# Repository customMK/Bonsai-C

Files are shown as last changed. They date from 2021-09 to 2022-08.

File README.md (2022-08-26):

# Bonsai C

Brought to you by customMK, Bonsai C is a family of open source microcontroller boards intended for custom mechanical keyboards using STM32F ARM microcontrollers. Designed to be a drop-in-replacement for Proton C rev 2 (and thus Pro Micros as well), Bonsai C incorporates several design and manufactring improvements, including being "JLCPCB-ready".

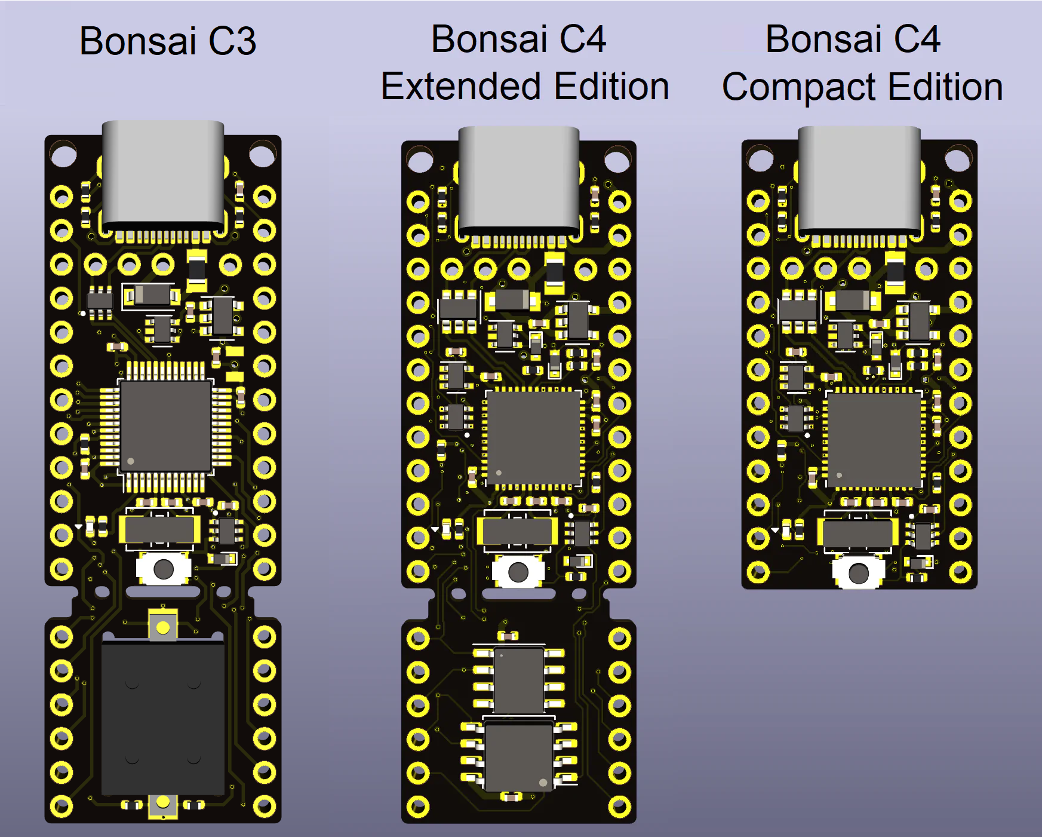
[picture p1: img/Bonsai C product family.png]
Bonsai C product family


# Bonsai C3

Bonsai C3 features an STM32F303 microcontroller, and has the exact same electrical functionality as the (now unavailable) Proton C. More info on Bonsai C3 can be found [here](https://github.com/customMK/Bonsai-C/tree/main/C3)

# Bonsai C4 Extended Edition

Bonsai C4 Extended Edition features an STM32F411 microcontroller. It is designed to be a drop-in-repalcement for Proton C, making it also compatible with ProMicro-based designs. The board is [available for purchase at customMK](https://shop.custommk.com/products/bonsai-c4-microcontroller-board?variant=41508980850884), and can be built through JLCPCB as well. In addition to the board being usable in DIY keyboard kits, Bonsai C4 can serve as a useful reference and starting point for keyboard designers planning to use STM32F411 becuase it incorporates the hardware necessary consistent USB DFU boot.

More info on Bonsai C4 Extended Edition can be found [here](https://github.com/customMK/Bonsai-C/tree/main/C4%20extended), as well as a Bonsai C4 product guide [here](https://custommk.github.io/#/Bonsai-C4/quick-start) (work in progress)

# Bonsai C4 Compact Edition

Bonsai C4 Compact Edition is electrically identical to the Bonsai C4 Extended Edition, however, the Compact Edition physically matches the form factor of a ProMicro instead of Proton C. While lower part of the Extended Edition can be snapped off to make it the size of a ProMicro, doing this removes the FRAM and Flash memory chips. On the Compact Edition, the FRAM and Flash memory chips are instead mounted to the back side of the PCB. The board is [available for purchase at customMK](https://shop.custommk.com/products/bonsai-c4-microcontroller-board?variant=41508980818116)

More info on Bonsai C4 Compact Edition can be found [here](https://github.com/customMK/Bonsai-C/tree/main/C4%20compact), as well as a Bonsai C4 product guide [here](https://custommk.github.io/#/Bonsai-C4/quick-start) (work in progress). There is also a [JLCPCB-ready version of the compact edition](https://github.com/customMK/Bonsai-C/tree/main/C4%20compact%20JLCPCB), which meets hole size and trace/space requirements for JLCPCB, and uses parts availalble through JLCPCB.

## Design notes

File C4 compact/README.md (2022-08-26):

# Bonsai C4 Compact Edition

Brought to you by customMK, Bonsai C4 Compact Edition is an open source microcontroller board featuring an STM32F411CEU6 microcontroller. It is designed to be a drop-in-replacement for Proton C rev 2 and Pro Micro. It has the same circuit as the Bonsai C4 Extended Edition, with the exception that the PCB is made shorter (to match the ProMicro length) and the on-board FRAM and flash memory are located on the back of the PCB. Bonsai C4 Compact Edtiion is most useful for pre-existing keyboard designs that only have the physical space available for a ProMicro (Kyria, Sofle, Lily58, etc.), while retaining the full capability of Bonsai C4 Extended Edtion (aside from the extra pins).

For a version of Bonsai C4 with more pins that matches the length of a Proton C, please see Bonsai C4 Extended Edition found [here](https://github.com/customMK/Bonsai-C/tree/main/C4%20extended)

## Contents

- [Images](#images)
- [Pinout and DMA streams](#pinout-and-dma-streams)
- [Bonsai C4 and JLCPCB](#bonsai-c4-and-jlcpcb)
- [Usage in split keyboards](#usage-in-split-keyboards)
- [License](#license)

## Images

Bonsai C4 schematic
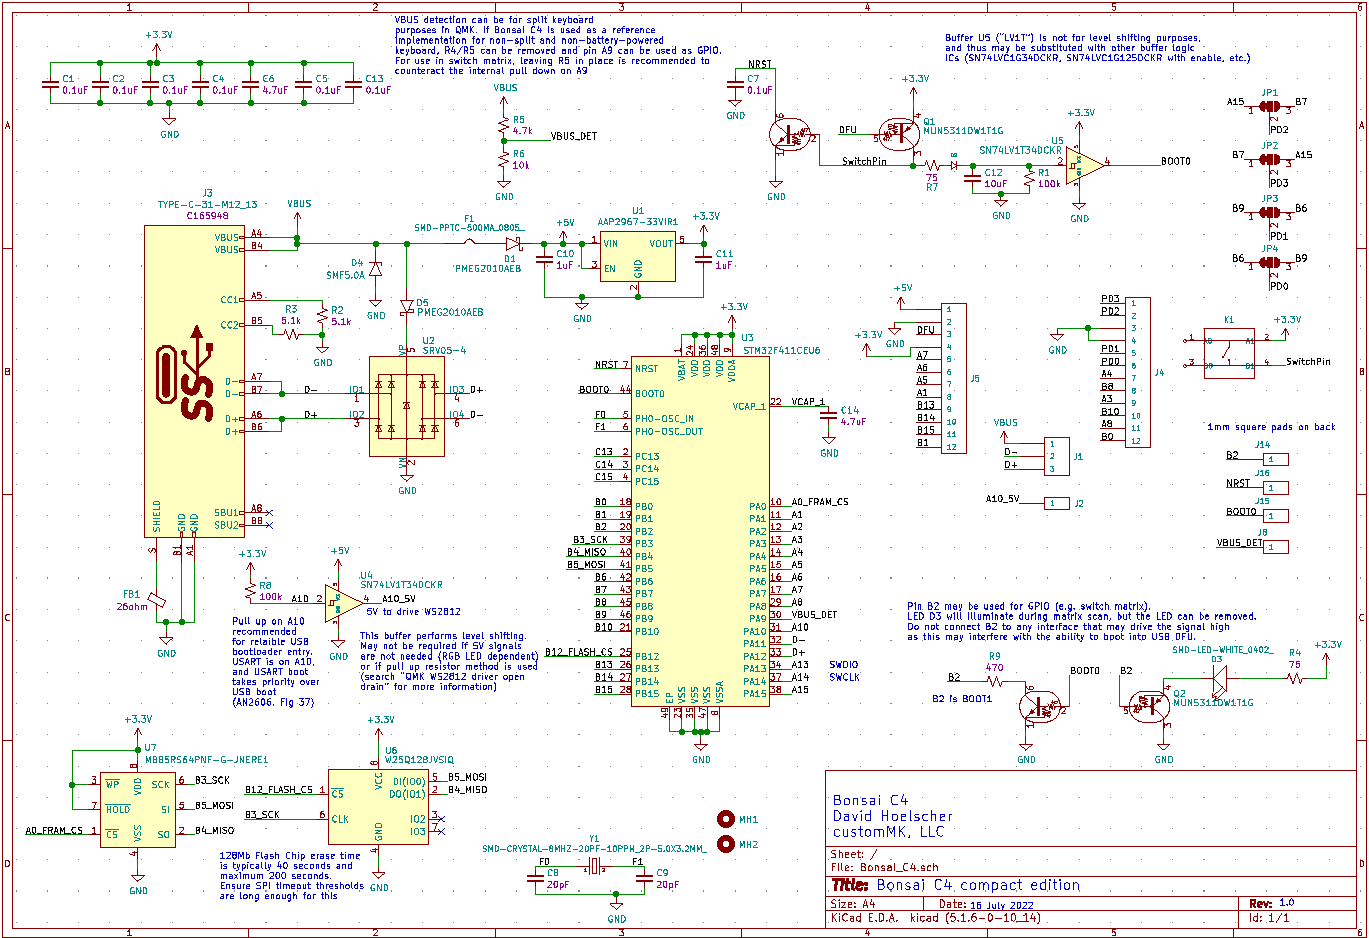
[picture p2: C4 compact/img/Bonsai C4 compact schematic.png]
Bonsai C4 Compact Edition schematic


Bonsai C4 compact edition PCB front photo

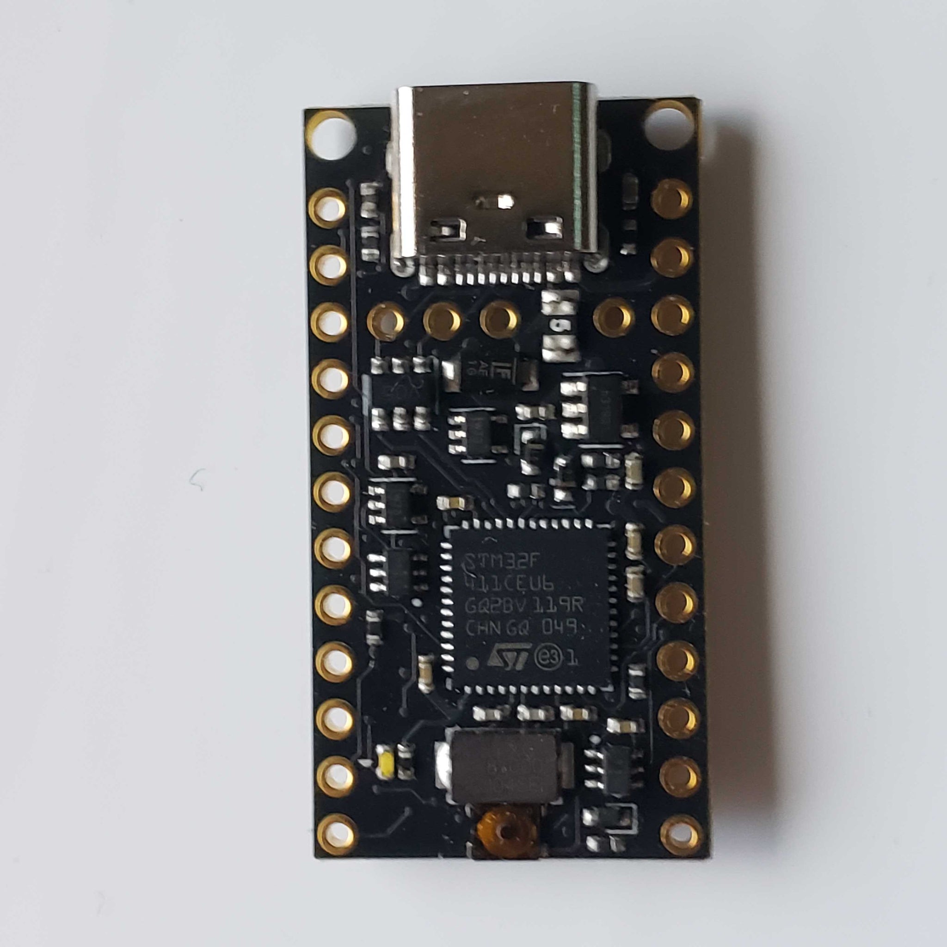
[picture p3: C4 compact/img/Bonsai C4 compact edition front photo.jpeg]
Bonsai C4 compact edition front photo


Bonsai C4 compact edition PCB back photo

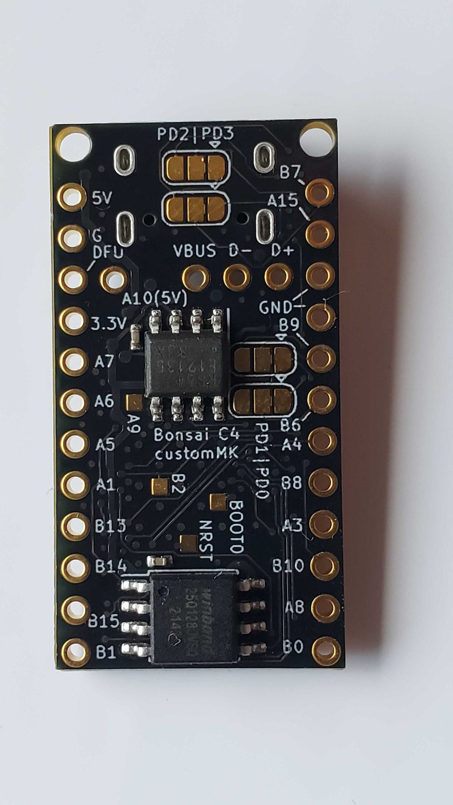
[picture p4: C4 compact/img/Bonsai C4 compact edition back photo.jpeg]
Bonsai C4 compact edition back photo


Bonsai C4 compact edition PCB front

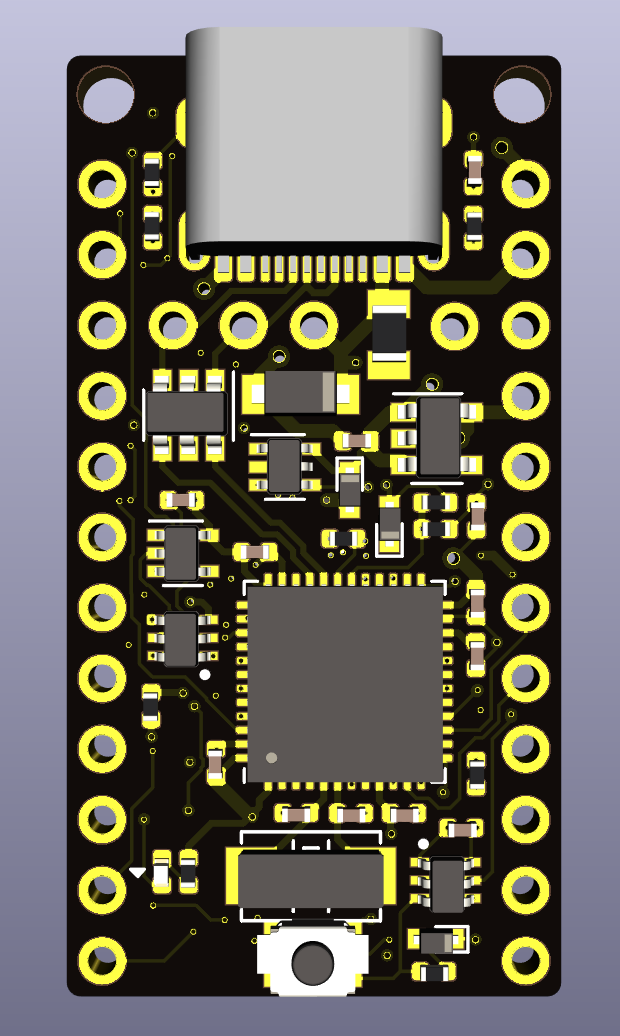
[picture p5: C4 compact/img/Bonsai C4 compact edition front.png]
Bonsai C4 compact edition front


Bonsai C4 compact edition PCB back

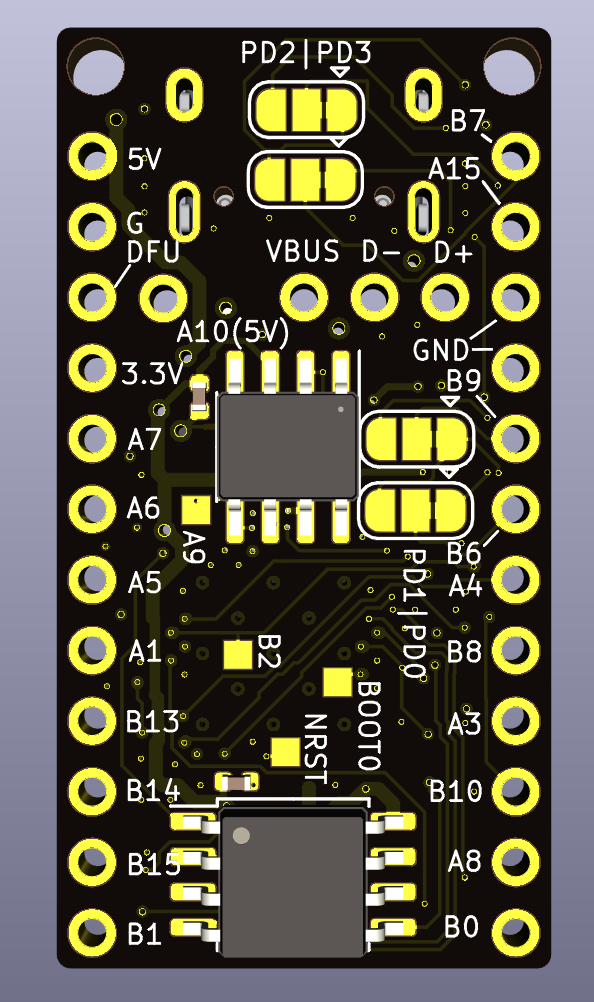
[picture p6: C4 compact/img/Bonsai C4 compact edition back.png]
Bonsai C4 compact edition back


# Pinout and DMA streams

Detailed pinout information, peripherals available on each pin, and a DMA stream management utility (to avoid DMA conflicts) can be found [here](https://docs.google.com/spreadsheets/d/1FY-Vt8GbN7uX89lh9176jPXvGJELREzGpuhMts9ds38/edit?usp=sharing).

# Bonsai C4 and JLCPCB

The STM32F411CEU6 has a large thermal pad on the back that prevents signal vias and traces from being placed under the microcontroller. As such, it is challenging to route all the traces in a way that fits the original form factor of the ProMicro/Proton C/Bonsai C. To keep the same form factor, via-in-pad is necessary. For consistent results in PCB production, this ususaly means doing a non-conductive via fill, cap, and planarize operation, which JLCPCB does not do. 

While the JLCPCB process may not be ideal for such a layout, we have now successfully built and tested prototype of Bonsai C4 Compact Edition built by JLCPCB (as of March 2022) at a cost of around $35 per PCB for five PCBs. Some parts had to be swapped out, hole sizes were changes, and traces modified, but the files used to produce these JLCPCB can be found [here](https://github.com/customMK/Bonsai-C/tree/main/C4%20compact%20JLCPCB)

# Usage in split keyboards

Limitations the STM32F411CEU6 are of particular concern to designers of split keyboards. Specifially, due to design decisions by ST, it is difficult to support all possible USART_TX pin locations on a single PCB. To help overcome this issue, solder bridges have been provided that allow certain pins to be swapped. Using ProMicro pinout labeling as a reference, only D0, D1, D2, and D3 are supported for half duplex split communications. Without any modification to Bonsai C4, ProMicro D0 (as B6 on the STM32F411) and D2 (as A15 on the STM32F411) are supported for soft serial use.

There are two pairs of solder bridges on the back of the board. Cutting the traces between these solder bridges (e.g. with a razor blade/Exacto knife/etc.) and then soldering across the opposite pads will swap either the D0 and D1 pins, or the D2 and D3 pins (depending on which pair of solder bridges is being modified).

It should be noted that the default of assignment of STM32F411 A15 to ProMicro D2 was done intentionally, even though technically, as a USART TX pin, it seems like it should be wired to ProMicro D3 instead. The reason for this is that many more keyboards tend to use ProMicro D2 for half duplex soft serial communciations (as compared to those which use ProMicro D3). Unlike Atmega32U4 on the ProMicro, the STM32F411 can only use the USART TX pin for this purpose, so the USART TX pin (A14) has been wired to ProMicro D2. The solder bridge opposite the USB connector can be used to swap these back, but it seems better to support the more common use by default without requiring modification to the board.

[Bonsai C4 Product Guide](https://custommk.github.io/#/Bonsai-C4/quick-start) (work in progress)

# Split keyboard reset

Many split keyboard designs use the same PCB for left and right sides. This requires one of the microcontroller boards to be flipped over for installation, which makes the reset button inaccessible. A simple workaround is to un-solder the reset switch, and then solder it between the DFU and GND pins. Temporarily connecting DFU and GND performs the same function as the reset switch; specifically, it reboots the microcontroller into bootloader mode.

## License

Open sourced under the [CERN 2.0 permissive license](LICENSE.md).

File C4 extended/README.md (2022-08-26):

# Bonsai C4 Extended Edition

Brought to you by customMK, Bonsai C4 Extended Edition is an open source microcontroller board featuring an STM32F411CEU6 microcontroller. It is designed to be a drop-in-replacement for Proton C rev 2 and Pro Micro. 

For a more compact version of Bonsai C4 that matches the length of a Pro Micro (for physical backwards compatibility reasons), please see Bonsai C4 Compact Edition found [here](https://github.com/customMK/Bonsai-C/tree/main/C4%20compact)

## Contents

- [Images](#images)
- [Pinout and DMA streams](#pinout-and-dma-streams)
- [Bonsai C4 and JLCPCB](#bonsai-c4-and-jlcpcb)
- [Usage in split keyboards](#usage-in-split-keyboards)
- [License](#license)

## Images

Bonsai C4 Extended Edition Schematic
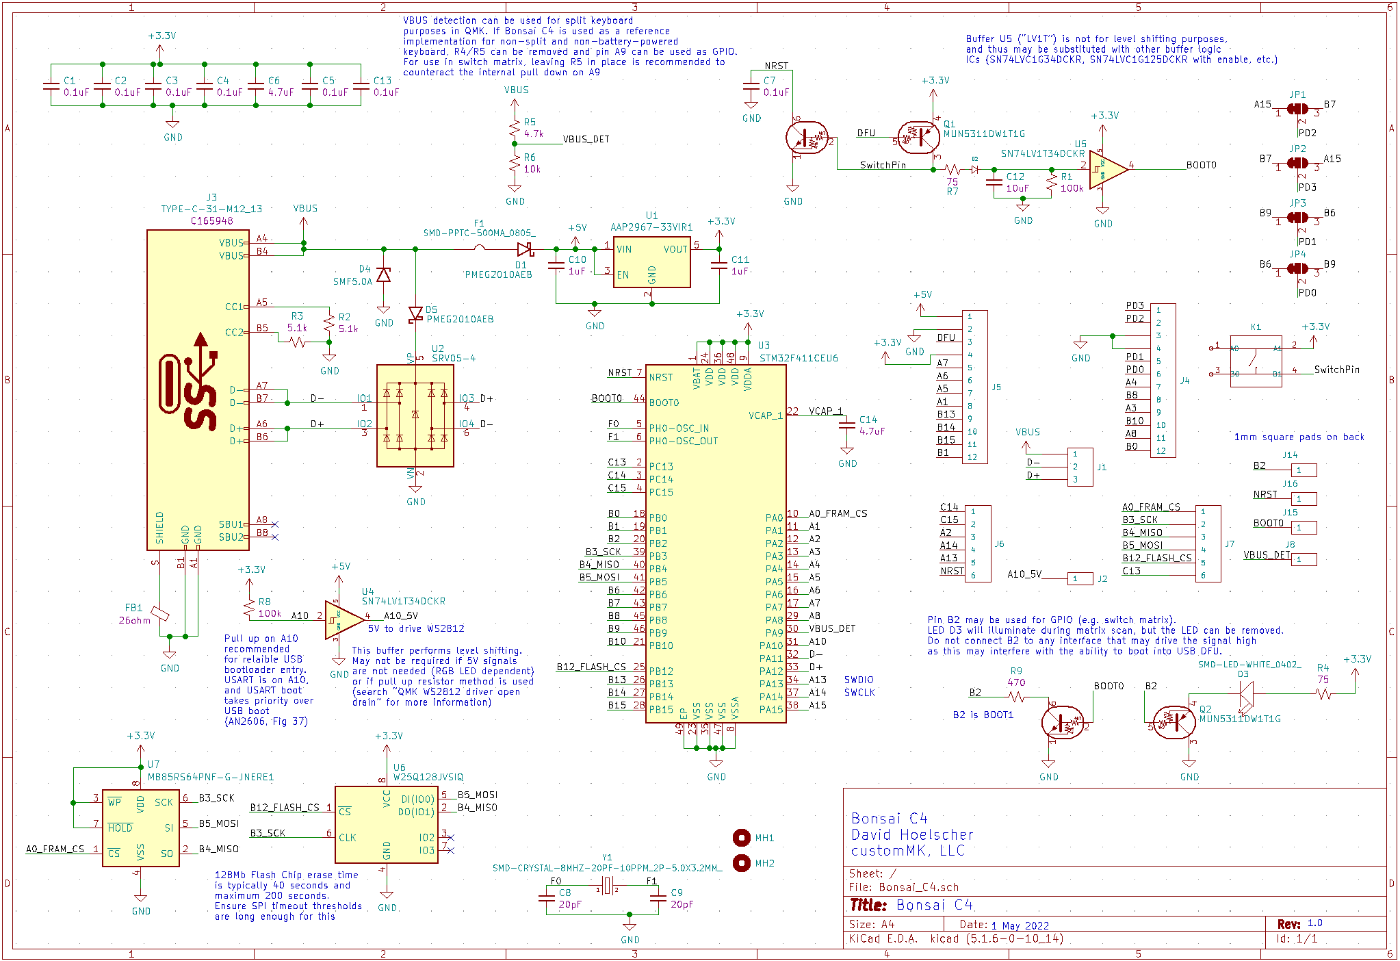
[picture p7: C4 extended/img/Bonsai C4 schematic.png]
Bonsai C4 Extended Edition schematic

Bonsai C4 Extended Edition front photo

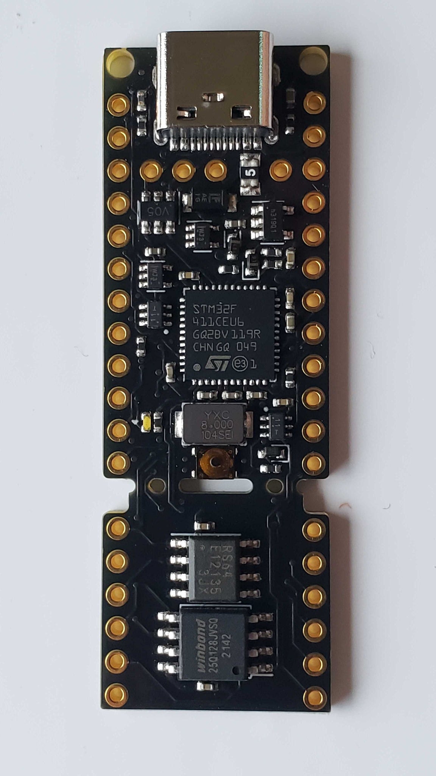
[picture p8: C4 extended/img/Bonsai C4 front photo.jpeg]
Bonsai C4 front photo

Bonsai C4 PCB Extended Edition back photo

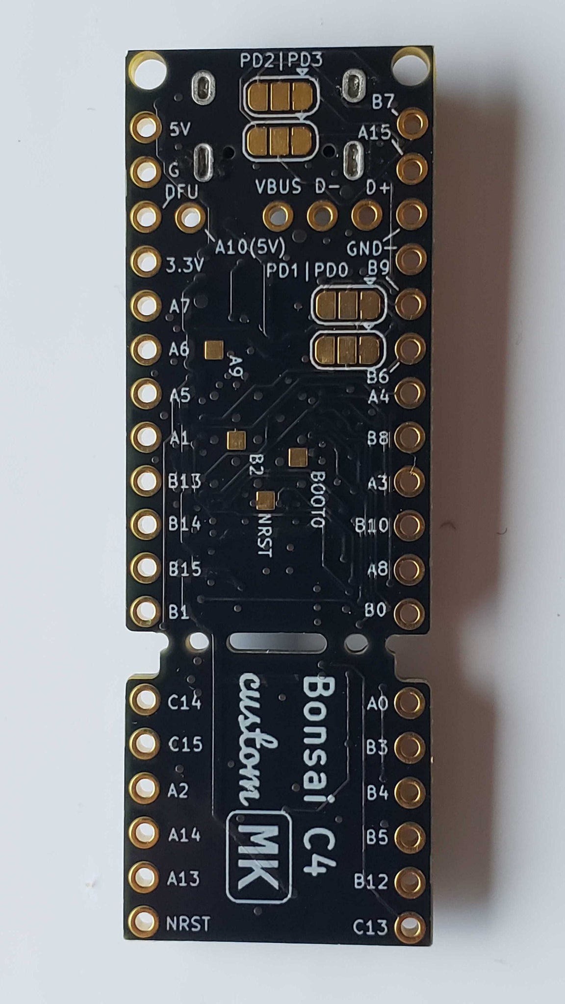
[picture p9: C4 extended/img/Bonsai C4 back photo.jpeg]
Bonsai C4 back photo

Bonsai C4 Extended Edition PCB front

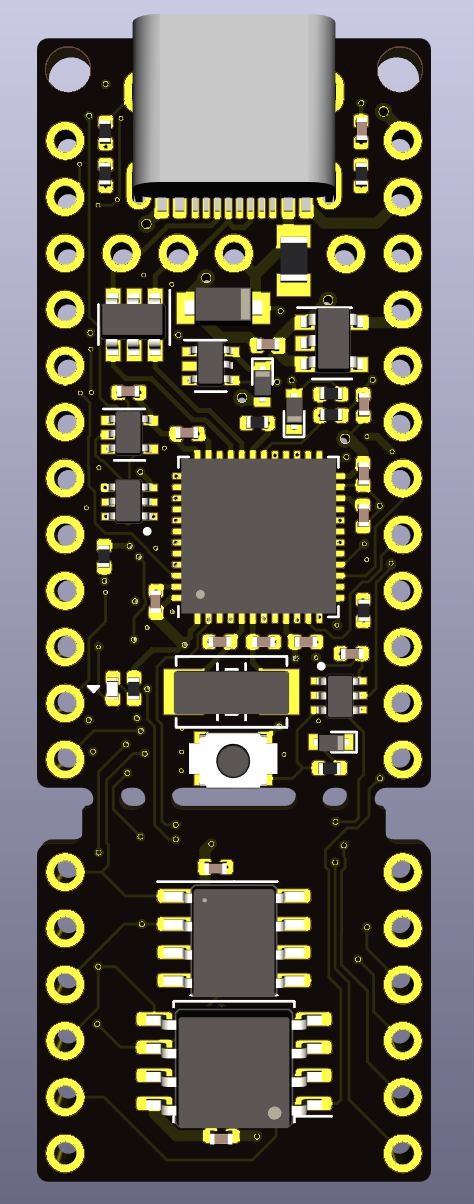
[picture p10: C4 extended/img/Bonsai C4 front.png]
Bonsai C4 front

Bonsai C4 PCB Extended Edition PCB back 

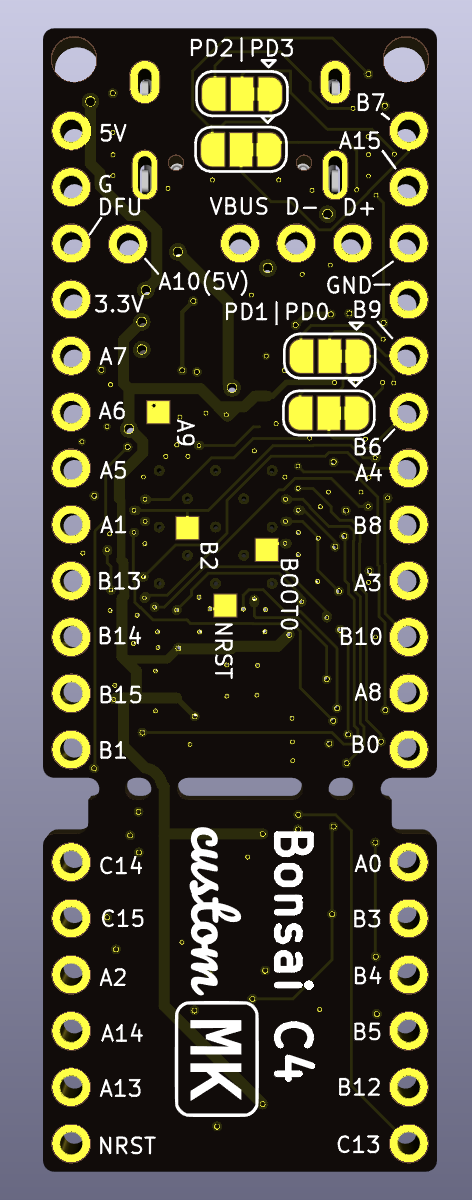
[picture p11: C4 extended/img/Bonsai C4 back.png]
Bonsai C4 back


# Pinout and DMA streams

Detailed pinout information, peripherals available on each pin, and a DMA stream management utility (to avoid DMA conflicts) can be found [here](https://docs.google.com/spreadsheets/d/1FY-Vt8GbN7uX89lh9176jPXvGJELREzGpuhMts9ds38/edit?usp=sharing).

# Bonsai C4 and JLCPCB

The STM32F411CEU6 has a large thermal pad on the back that prevents signal vias and traces from being placed under the microcontroller. As such, it is challenging to route all the traces in a way that fits the original form factor of the ProMicro/Proton C/Bonsai C. To keep the same form factor, via-in-pad is necessary. For consistent results in PCB production, this ususaly means doing a non-conductive via fill, cap, and planarize operation, which JLCPCB does not do. 

While the JLCPCB process may not be ideal for such a layout, we have now successfully built and tested prototype of Bonsai C4 Compact Edition built by JLCPCB (as of March 2022) at a cost of around $35 per PCB for five PCBs. Some parts had to be swapped out, hole sizes were changes, and traces modified, but the files used to produce these JLCPCB can be found [here](https://github.com/customMK/Bonsai-C/tree/main/C4%20compact%20JLCPCB)

# Usage in split keyboards

Limitations the STM32F411CEU6 are of particular concern to designers of split keyboards. Specifially, due to design decisions by ST, it is difficult to support all possible USART_TX pin locations on a single PCB. To help overcome this issue, solder bridges have been provided that allow certain pins to be swapped. Using ProMicro pinout labeling as a reference, only D0, D1, D2, and D3 are supported for half duplex split communications. Without any modification to Bonsai C4, ProMicro D0 (as B6 on the STM32F411) and D2 (as A15 on the STM32F411) are supported for soft serial use.

There are two pairs of solder bridges on the back of the board. Cutting the traces between these solder bridges (e.g. with a razor blade/Exacto knife/etc.) and then soldering across the opposite pads will swap either the D0 and D1 pins, or the D2 and D3 pins (depending on which pair of solder bridges is being modified).

It should be noted that the default of assignment of STM32F411 A15 to ProMicro D2 was done intentionally, even though technically, as a USART TX pin, it seems like it should be wired to ProMicro D3 instead. The reason for this is that many more keyboards tend to use ProMicro D2 for half duplex soft serial communciations (as compared to those which use ProMicro D3). Unlike Atmega32U4 on the ProMicro, the STM32F411 can only use the USART TX pin for this purpose, so the USART TX pin (A14) has been wired to ProMicro D2. The solder bridge opposite the USB connector can be used to swap these back, but it seems better to support the more common use by default without requiring modification to the board.

[Bonsai C4 Product Guide](https://custommk.github.io/#/Bonsai-C4/quick-start) (work in progress)

# Split keyboard reset

Many split keyboard designs use the same PCB for left and right sides. This requires one of the microcontroller boards to be flipped over for installation, which makes the reset button inaccessible. A simple workaround is to un-solder the reset switch, and then solder it between the DFU and GND pins. Temporarily connecting DFU and GND performs the same function as the reset switch; specifically, it reboots the microcontroller into bootloader mode.

## License

Open sourced under the [CERN 2.0 permissive license](LICENSE.md).

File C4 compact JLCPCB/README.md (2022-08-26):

# Bonsai C4 Compact Edition, JLCPCB

Brought to you by customMK, Bonsai C4 Compact Edition for JLCPCB is the same as Bonsai C4 Compact Edition, except minor adjustments were made to comply with JLCPCB trace/space and hole size requirements, as well as to use parts generally available through JLCPCB

Note that the EEPROM/FRAM chip and the flash memory chips are on the back side of this board. They can be soldered on by hand using JLCPCB's economical assembly service, or JLCPCB can solder them on at higher expense using their standard assembly service.

## Contents

- [Images](#images)
- [License](#license)

## Images

Bonsai C4 Compact Edition schematic
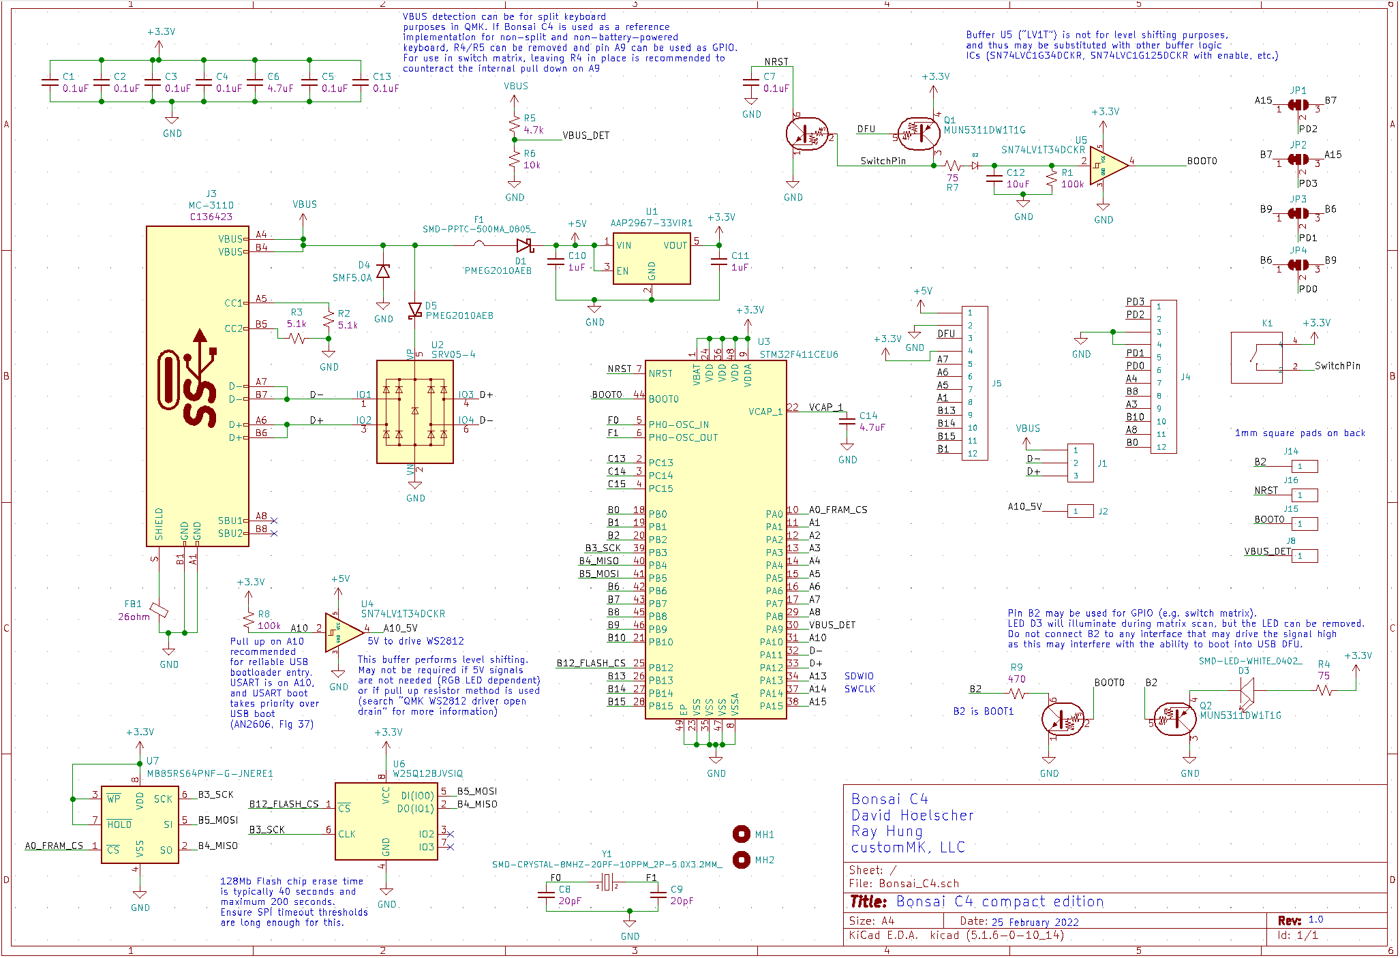
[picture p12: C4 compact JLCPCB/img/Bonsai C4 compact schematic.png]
Bonsai C4 compact edition schematic


Bonsai C4 Compact Edition front produced by JLCPCB

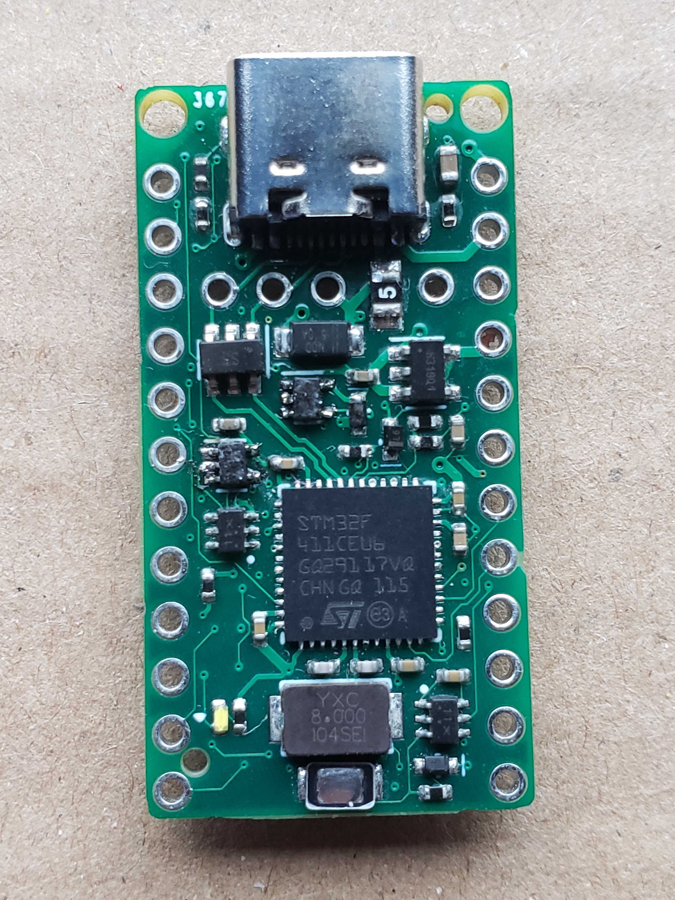
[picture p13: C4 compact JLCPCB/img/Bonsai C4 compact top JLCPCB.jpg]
Bonsai C4 compact edition front

Bonsai C4 Compact Edition back produced by JLCPCB

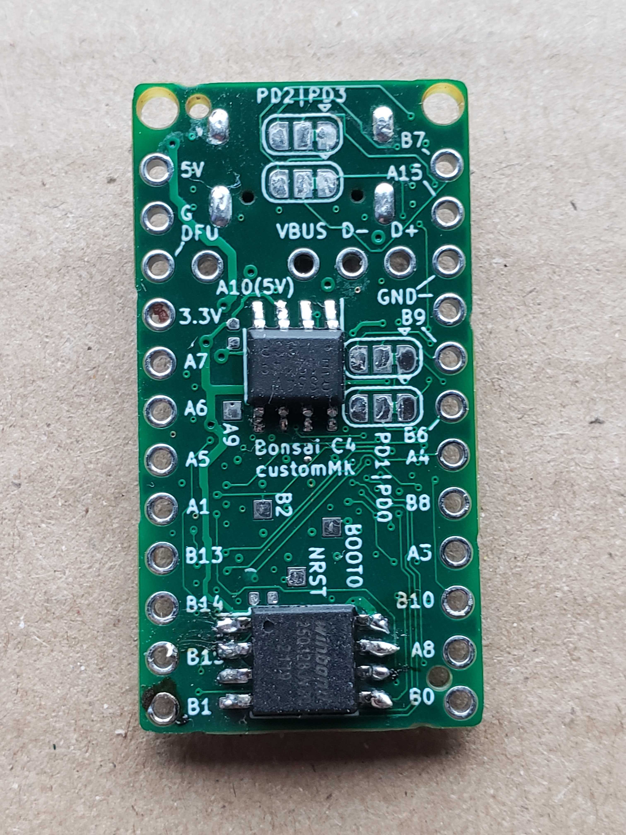
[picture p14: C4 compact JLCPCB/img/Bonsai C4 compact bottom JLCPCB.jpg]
Bonsai C4 compact edition back


## License

Open sourced under the [CERN 2.0 permissive license](LICENSE.md).

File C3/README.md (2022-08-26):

# Bonsai C3

## Contents

- [Images](#images)
- [Background](#background)
- [Comparison to Proton C](#comparison-to-proton-c)
- [Build information](#build-information)
- [License](#license)

## Images

Bonsai C3 schematic

Bonsai C3 schematic

Bonsai C3 fabricated by JLCPCB (disregard the extra width, 20mm minimum width used to be JLCPCB requirement)



Bonsai C3 PCB front

Bonsai C3 front

Bonsai C3 PCB back

Bonsai C3 back

Bonsai C3 layers

Bonsai C3 layers

## Background

Bonsai C3 is a general-purpose ARM-based microcontroller board. It was designed to help with the protoype and development of mechanical keyboards, but is versatile enough to be used in a variety of other applications. Mechanical keyboards can use Bonsai C3 as a "plug in" microcontroller board to their own designs sans-microcontroller, or they can incorporate the Bonsai C schmatic and layout directly into a complete keyboard PCB design.

## Comparison to Proton C

Bonsai C3 is designed to be a drop-in-replacement to Proton C, and as such, they are functionally equivalent. However, there are several subtle design differences in contrast to Proton C:

<ul>
  <li>Bonsai C3 uses only parts in the JLCPCB SMT library (including the USB C connector)</li>
  <li>Bonsai C3’s USB data traces are shorter and more direct</li>
  <li>Bonsai C3's USB data traces are designed for the correct impedance, using a 4 layer board design with power and ground planes.</li>
  <li>Bonsai C3’s crystal clock lines are shorter and more direct</li>
  <li>Bonsai C3 adds a ferrite between USB shield and ground, improving EMI (radiated susceptibility and radiated emissions)</li>
  <li>Bonsai C3 connects USB VBUS to the ESD chip instead of the +5V (+5V is polyfuse-limited and reverse-diode-protected)</li>
  <li>Bonsai C3 has correct labeling of the C14 and C15 pads (they are currently swapped in Proton C documentation and PCB silkscreen labeling)</li>
  <li>Bonsai C3 uses ceramic bulk decoupling capacitors instead of tantalum capacitors</li>
  <li>Bonsai C3 avoids via-in-pad (note: via-in-pad without non-conductive epoxy fill can cause solder joints to become starved of solder during assembly)</li>
</ul>

## Build information

Bonsai C3 is a four layer PCB design.

If you plan to fabricate the Bonsai C3 design "as-is" without modificiation, within the "build" folder are two different zip files to make it easier to achieve this:
<ul>
<li><b>Bonsai_C3_Gerbers_Only.zip</b> contains the Gerber files only. If you plan to solder parts on your own, you can simply take the zip file, send it to the PCB fab of your choice, and get boards made.</li>

<li><b>Bonsai_C3_PCBA.zip</b> has the set of files needed to make fully-assembled PCBs; this includes the Gerber files above as well as a BOM and position file for assembly. These files can be provided to most of PCB assembly shops when ordering fully assembled boards. Depending on the assembly shop, it may be necessary to use alternative parts for some of the passive components (depending on where components are sourced from).</li>
</ul>
Included are also JLCPCB-ready BOM and position files, so uploading the design can be done by simply uploading the Gerber zip, BOM file, and CPL file to JLCPCB. However, from time to time, parts may go in and out of stock without suitable replacements in the JLCPCB library, necessitating some tailoring and/or hand soldering of components.

To use the lower cost STM32F303CB microcontroller instead of STM32F303CC, simply edit the BOM file; the footprint is identical between the CC and CB variants.

If you are unable to source the microcontroller directly, keep in mind that with the right equipment (hot air rework station) it is possible to transplant microcontroller from other boards you may have. If you plan to program (and let end users reflash) the microcontroller over USB by using QMK Toolbox, you will want you select a microcontroller that includes an embedded USB bootloader, of which there are relatively few options to choose from:

STM USB DFU

See [here](https://github.com/qmk/qmk_firmware/issues/4194) for more information, particularly yiancar's comment on Oct 22, 2018. 

If you are willing to forego programming over the USB connector, and instead find it acceptable to use a low-cost SWD programmer (like ST-LINK) to flash new firmware onto the microcontroller, then there are many many more microcontroller options to choose from.

## License

Open sourced under the [CERN 2.0 permissive license](LICENSE.md).

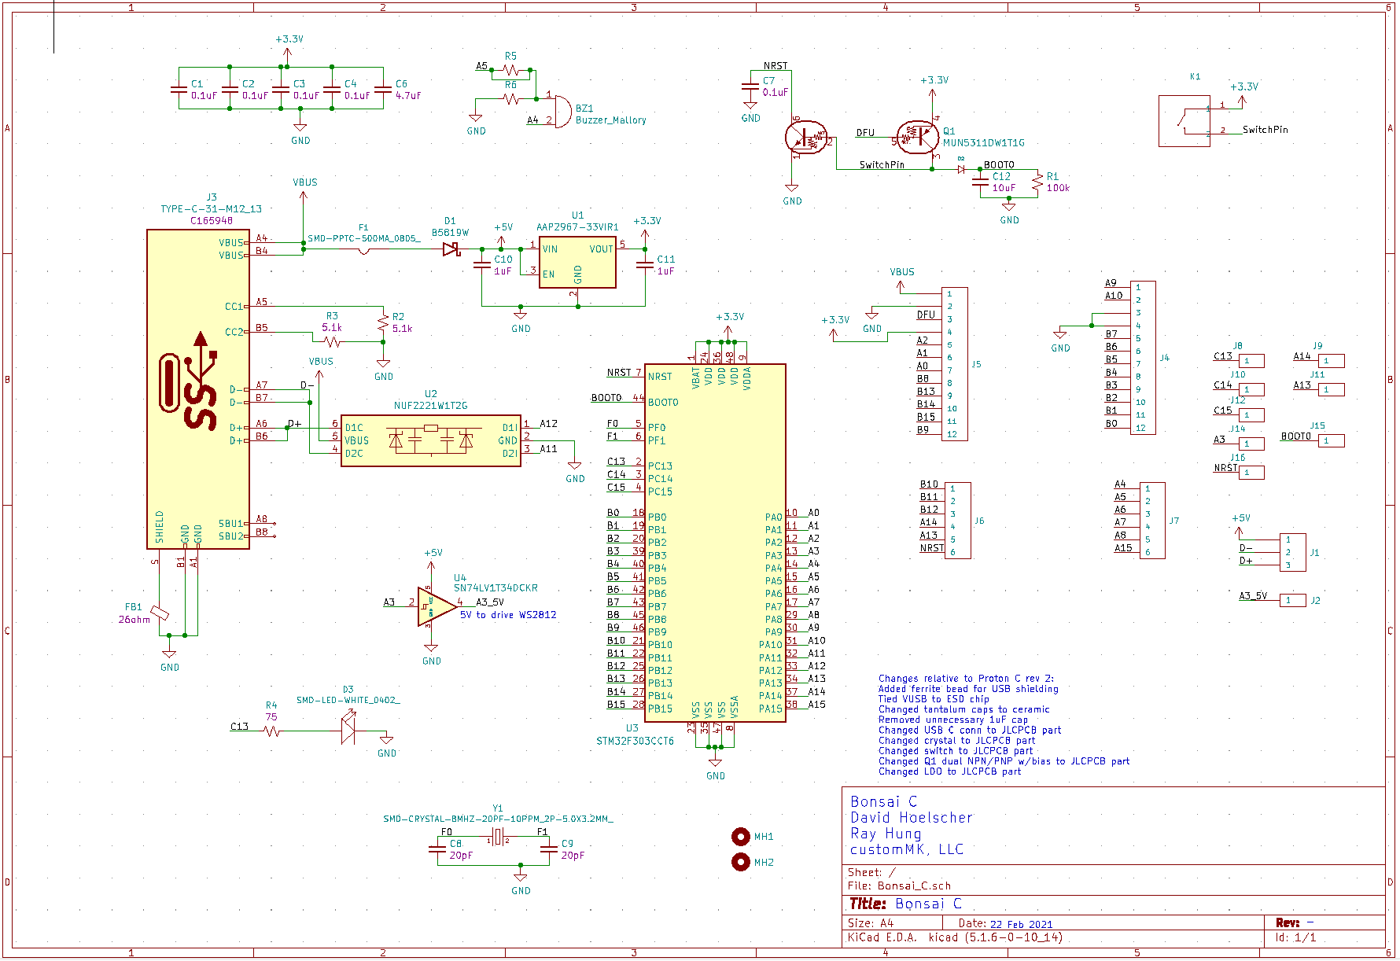
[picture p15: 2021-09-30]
C3/img/Bonsai C schematic.png

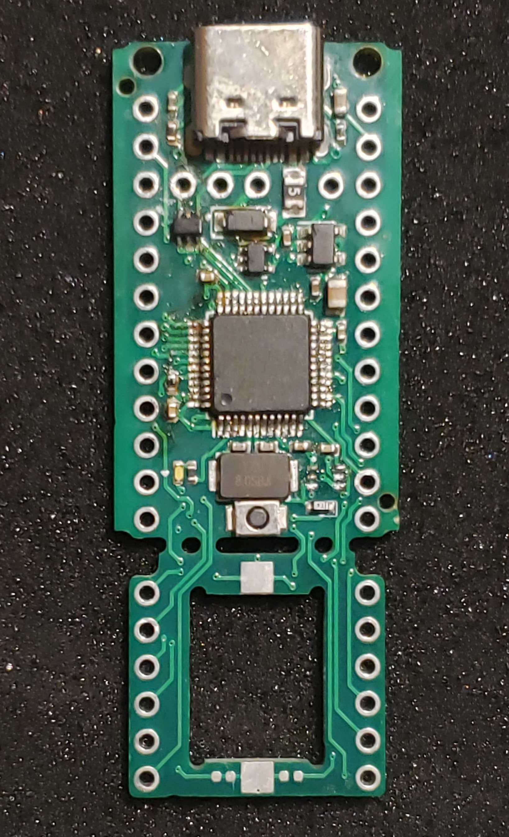
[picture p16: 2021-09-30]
C3/img/Bonsai C JLCPCB photo.jpg

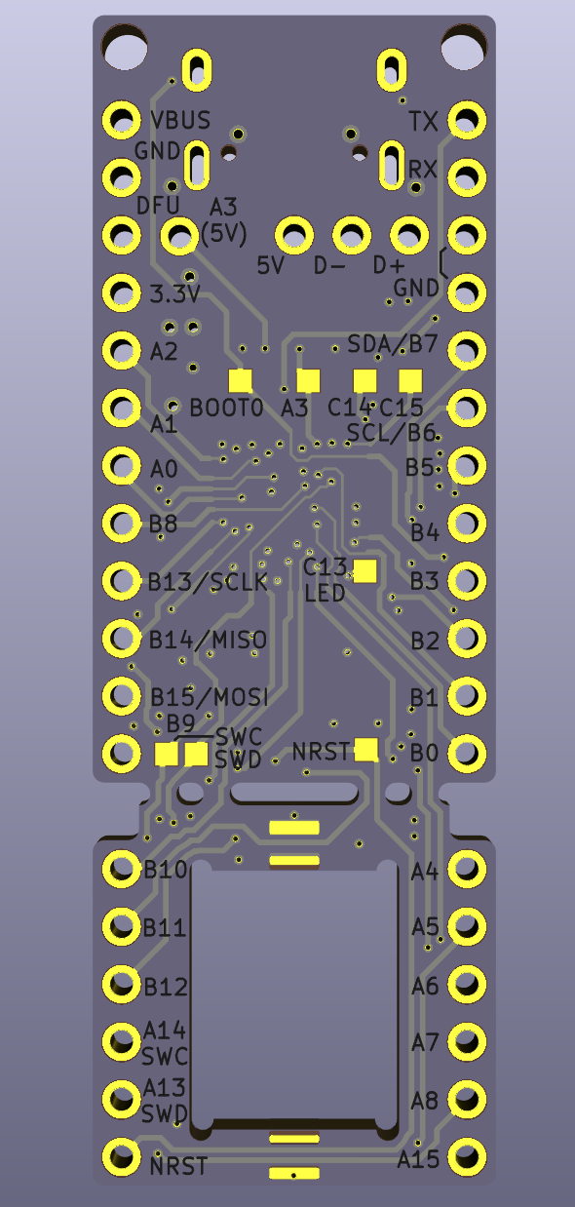
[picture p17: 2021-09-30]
C3/img/Bonsai C back.png

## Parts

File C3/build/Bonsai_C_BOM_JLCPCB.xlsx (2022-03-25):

Bonsai_C_BOM
Designator | Footprint | JLCPCB Part # | Comment | Mfg | Proton C MPN (for reference only) | Proton C Mfg (for reference only)
BZ1 | Buzzer_Mallory | C201047 | KLJ-1102 | KELIKING | AST1109MLTRQ | Mallory
C1, C2, C3, C4, C7 | cap_100nF_16v_0402 | C1525 | CL05B104KO5NNNC | Samsung
C6 | cap_4.7uF_25v_0805 | C1779 | CL21A475KAQNNNE | Samsung
C8, C9 | cap_20pF_50v_0402 | C1554 | 0402CG200J500NT | Guangdong Fenghua Advanced Tech
C10, C11 | cap_1uF_10v_0402 | C52923 | CC0402KRX5R6BB105 | Yageo
C12 | cap_10uF_10v_0402 | C19702 | CL10A106KP8NNNC | Samsung
D1 | B5819W | C8598 | B5819W | Changjiang Electronics Tech
D2 | 1N4148 | C68948 | 1N4148X-TP | Micro Commercial Components
D3 | SMD-LED-WHITE_0402_ | C74342 | 16-219A/T2D-AR2T1QY/3T | Everlight Elec
F1 | SMD-PPTC-500MA_0805_ | C66452 | SMD0805-050 | TECHFUSE
FB1 | fb_0402_26ohm | C668229 | CBG100505U260T | FH
J3 | TYPE-C-31-M12_13 | C165948 | TYPE-C-31-M-12 | Korean Hroparts Elec | 105450-0101 | Molex
K1 | SMD-SWITCH-TACTILE-SPST-NO_2P-2.5MMx3.0MM_ | C231329 | B3U-1000P | Omron | TBE-Q-T/R | Diptronics
Q1 | MUN5311DW1T1G | C152542 | MUN5311DW1T1G | ON Semiconductor | MUN5332DW1T1G | ON Semiconductor
R1 | r_100k_0402_1p | C25741 | 0402WGF1003TCE | Uniroyal
R2, R3 | r_5.1k_0402_1p | C25905 | 0402WGF5101TCE | Uniroyal
R4 | r_75_0402_1p | C25133 | 0402WGF750JTCE | Uniroyal
U1 | AAP2967-33VIR1 | C370742 | AAP2967-33VIR1 | Eutech Microelectronics | MIC5504-3.3YM5 | Microchip
U2 | NUF2221W1T2G | C274624 | NUF2221W1T2G | ON Semiconductor | NUF2221W1T2G | ON Semiconductor
U3 | STM32F303CCT6 | C81523 | STM32F303CCT6 | STMicroelectronics | STM32F303CCT6 | STMicroelectronics
U4 | SN74LV1T34DCKR | C78541 | SN74LV1T34DCKR | Texas Instruments | SN74LV1T34DCKR | Texas Instruments
Y1 | SMD-CRYSTAL-8MHZ-20PF-10PPM_2P-5.0X3.2MM_ | C115962 | X50328MSB2GI | Yangxing Tech | ABM3B-8.000MHZ-10-1-U-T | Abracon

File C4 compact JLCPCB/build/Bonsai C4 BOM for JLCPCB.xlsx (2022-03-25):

Table 1
Comment | Designator | Footprint | LCSC Part Number
cap_100nF_16v_0402 | C1,C2,C3,C4, C7 | C_0402_1005Metric | C1525
cap_20pF_50v_0402 | C8,C9 | C_0402_1005Metric | C1554
cap_1uF_10v_0402 | C10,C11 | C_0402_1005Metric | C52923
cap_10uF_10v_0402 | C12 | C_0402_1005Metric | C19702
cap_4.7uF_10v_0402 | C6,C14 | C_0402_1005Metric | C23733
1N4148 | D2 | D_SOD-523 | C68948
SMD-LED-WHITE_0402_ | D3 | LED_0402 | C74342
SMF5.0A | D4 | D_SOD-123FL | C193402
PMEG2010AEB | D1,D5 | D_SOD-523 | C282563
SMD-PPTC-500MA_0805_ | F1 | F0805 | C66452
fb_0402_26ohm | FB1 | R_0402_1005Metric | C668229
MC-311D | J3 | MC-311D | C136423
SMD-SWITCH-TACTILE-SPST-NO_2P-2.0MMx3.5MM_ | K1 | SW2-SMD-2.0X3.5X0.45MM | C398737
MUN5311DW1T1G | Q1,Q2 | SOT-363_SC-70-6_SC-88 | C152542
r_100k_0402_1p | R1,R8 | R_0402_1005Metric | C25741
r_5.1k_0402_1p | R2,R3 | R_0402_1005Metric | C25905
r_75_0402_1p | R4,R7 | R_0402_1005Metric | C25133
r_4.7k_0402_1p | R5 | R_0402_1005Metric | C25900
r_10k_0402_1p | R6 | R_0402_1005Metric | C25744
r_470_0402_1p | R9 | R_0402_1005Metric | C25117
AAP2967-33VIR1 | U1 | SOT-23-5 | C370742
SRV05-4 | U2 | SOT-23-6 | C85364
STM32F411CEU6 | U3 | QFN-48-1EP_7x7mm_P0.5mm_EP5.6x5.6mm_ThermalVias | C60420
SN74LV1T34DCKR | U4,U5 | SOT-353_SC-70-5 | C78541
SMD-CRYSTAL-8MHZ-20PF-10PPM_2P-5.0X3.2MM_ | Y1 | X2-SMD-5.0X3.2X1.3MM | C115962

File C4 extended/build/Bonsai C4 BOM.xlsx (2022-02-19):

Table 1
RefDes | Value | Footprint | MPN | Mfg | Qty
C1-C5, C7, C13 | cap_100nF_16v_0402 | C_0402_1005Metric | CL05B104KO5NNNC | Samsung | 7
C8, C9 | cap_20pF_50v_0402 | C_0402_1005Metric | 0402CG200J500NT | Guangdong Fenghua Advanced Tech | 2
C10, C11 | cap_1uF_10v_0402 | C_0402_1005Metric | CC0402KRX5R6BB105 | Yageo | 2
C12 | cap_10uF_10v_0402 | C_0402_1005Metric | CL10A106KP8NNNC | Samsung | 1
C6, C14 | cap_4.7uF_10v_0402 | C_0402_1005Metric | CL05A475MP5NRNC | Samsung | 2
D2 | 1N4148 | D_SOD-523 | 1N4148X-TP | Micro Commercial Components | 1
D3 | SMD-LED-WHITE_0402_ | LED_0402 | 16-219A/T2D-AR2T1QY/3T |  | 1
D4 | SMF5.0A | D_SOD-123FL | SMF5.0A |  | 1
D1, D5 | PMEG2010AEB | D_SOD-523 | PMEG2010AEB |  | 2
F1 | SMD-PPTC-500MA_0805_ | F0805 | SMD0805-050 |  | 1
FB1 | fb_0402_26ohm | R_0402_1005Metric | CBG100505U260T | FH | 1
J3 | TYPE-C-31-M12_13 | TYPE-C-31-M-12 | TYPE-C-31-M-12 | Korean Hroparts Elec | 1
K1 | SMD-SWITCH-TACTILE-SPST-NO_4P-3.0MMx2.6MM_ | SW4-SMD-3.0X2.6X0.7MM | EVPAF7B70 |  | 1
Q1, Q2 | MUN5311DW1T1G | SOT-363_SC-70-6_SC-88 | MUN5311DW1T1G (alternate: MUN5332DW1T1G) |  | 2
R1, R8 | r_100k_0402_1p | R_0402_1005Metric | 0402WGF1003TCE |  | 2
R2, R3 | r_5.1k_0402_1p | R_0402_1005Metric | 0402WGF5101TCE |  | 2
R4, R7 | r_75_0402_1p | R_0402_1005Metric | 0402WGF750JTCE | Uniroyal | 2
R5 | r_4.7k_0402_1p | R_0402_1005Metric | 0402WGF4701TCE |  | 1
R6 | r_10k_0402_1p | R_0402_1005Metric | 0402WGF1002TCE |  | 1
R9 | r_470_0402_1p | R_0402_1005Metric | 0402WGF4700TCE | Uniroyal | 1
U1 | AAP2967-33VIR1 | SOT-23-5 | AAP2967-33VIR1 |  | 1
U2 | SRV05-4 | SOT-23-6 | SRV05-4 |  | 1
U3 | STM32F411CEU6 | QFN-48-1EP_7x7mm_P0.5mm_EP5.6x5.6mm | STM32F411CEU6 |  | 1
U4, U5 | SN74LV1T34DCKR | SOT-353_SC-70-5 | SN74LV1T34DCKR |  | 2
U6 | W25Q128JVSIQ | SOIC-8_5.23x5.23mm_P1.27mm | W25Q128JVSIQ |  | 1
U7 | MB85RS64PNF-G-JNERE1 | SOP-8_3.9x4.9mm_P1.27mm | MB85RS64PNF-G-JNERE1 |  | 1
Y1 | SMD-CRYSTAL-8MHZ-20PF-10PPM_2P-5.0X3.2MM_ | X2-SMD-5.0X3.2X1.3MM | X50328MSB2GI |  | 1

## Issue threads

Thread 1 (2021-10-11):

JLCPCB 20mm wide version showing up as 19.78mm wide in the JLCPCB ordering form.

Aleblazer, 2021-10-11:
Uploading the JLCPCB 20mm gerbers to the JLCPCB ordering page is showing the width at 19.78mm, this is preventing selection of SMT services.
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
.

infinityis, 2021-10-17:
Width has been corrected to 20mm. Also changed the 20mm width to be on the bottom half so that the main section width is normal in case the bottom half is unused and removed manually.

Closed 2021-10-17.

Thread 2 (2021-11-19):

documentation / wiki clarification on the split keyboard status

alexmaloteaux, 2021-11-19:
HI,

after ordering the part for a bonsai-c , mainly to deal with the 32k limitation of the pro-micro, i realized  that the proton-c is actually not yet compatible with split keyboard like corne, lotus58 ... when using qmk

Is it possible to clarify the actual status of bonsai-c regarding split keyboard witj qmk and have it eventually in the readme ?

I guess that ` a drop-in-replacement for Proton C rev 2` is enough for most people, but im pretty new to qmk and was not  aware of that limitation.

Best Regards

infinityis, 2021-11-19:
Yes, I can add some clarifications to the readme in that regard. Unfortunately it seems like almost any STM32F-based replacement may have some sort of tradeoffs with regards to compatibility.

I do want to point out that (based on my current understanding) you can achieve some compatibility following this guide from Drashna for Kyria (and other split keyboards), which gets it working by leave out one header pin and adding add two wires (one for split comms, one for RGB) https://github.com/qmk/qmk_firmware/blob/develop/keyboards/splitkb/kyria/readme.md#proton-c-conversion-guide

Something else that should be do-able is to create a separate version of Bonsai C; instead of targeting compatibility with Proton C it is can be made specifically as a drop-in replacement for split keyboards. That, or (like I'm doing on the Bonsai C4 design now) adding a few solder bridges; this could make it very easy to switch between Proton C compatibility and split keyboard compatibility.

Thoughts? I don't have a split keyboard, so if the incompatibility extends any further than the modifications I linked to, let me know or send links to more information so I can try to accommodate.

alexmaloteaux, 2021-11-19:
ok, once i get mine soldered, i will review and test on a lotus58 first and report here.
There is another wiring example in this project :

https://github.com/ItsWaffIe/waffle_corne.

The misleading documentation comes actually from qmk  wiki where they claim the support is partial, upcoming...

https://beta.docs.qmk.fm/using-qmk/hardware-features/proton_c_conversion
https://qmk.fm/proton-c/

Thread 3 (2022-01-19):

stm32f303cct6 dfu mode not detected

alexmaloteaux, 2022-01-19:
hi i have soldered 3 board with stm32f303cct6.

and after spending a fair amount of time i m convinced that the soldering is ok.

However when i press the reset button on each board, im seeing those message below:
Did the designer faced such issue ?

sdw works with an stlink v2, is it possible to have the command to properly flash the bootloader and the bin file ?

tx :)

```
[57189.443024] usb 4-4: new full-speed USB device number 109 using xhci_hcd
[57189.443154] usb 4-4: Device not responding to setup address.
[57189.663174] usb 4-4: Device not responding to setup address.
[57189.882941] usb 4-4: device not accepting address 109, error -71
[57189.882997] usb usb4-port4: unable to enumerate USB device
[57239.253870] razeraccessory: Response doesn't match request. Start Marker: 01 id: 1f Num Params: 1d Reserved: 0f Command: 03 Params: 0000000007f90600f90600f90600f906 .
[57249.582952] usb 4-4: new full-speed USB device number 110 using xhci_hcd
[57249.732995] usb 4-4: device descriptor read/64, error -71
[57250.002975] usb 4-4: device descriptor read/64, error -71
[57250.273023] usb 4-4: new full-speed USB device number 111 using xhci_hcd
[57250.432941] usb 4-4: device descriptor read/64, error -71
[57250.723041] usb 4-4: device descriptor read/64, error -71
[57250.852961] usb usb4-port4: attempt power cycle
[57251.343017] usb 4-4: new full-speed USB device number 112 using xhci_hcd
[57251.343188] usb 4-4: Device not responding to setup address.
[57251.563194] usb 4-4: Device not responding to setup address.
[57251.783002] usb 4-4: device not accepting address 112, error -71
[57251.933017] usb 4-4: new full-speed USB device number 113 using xhci_hcd
[57251.933154] usb 4-4: Device not responding to setup address.
[57252.153153] usb 4-4: Device not responding to setup address.
[57252.372921] usb 4-4: device not accepting address 113, error -71
[57252.372978] usb usb4-port4: unable to enumerate USB device
```

alexmaloteaux, 2022-01-19:
closing, i have been scamed by a seller on aliexpress and the chip where labeled stm32f303cct6 but CubeProgrammer was detecting them as stm32f101/stm32f103.

Closed 2022-01-19.

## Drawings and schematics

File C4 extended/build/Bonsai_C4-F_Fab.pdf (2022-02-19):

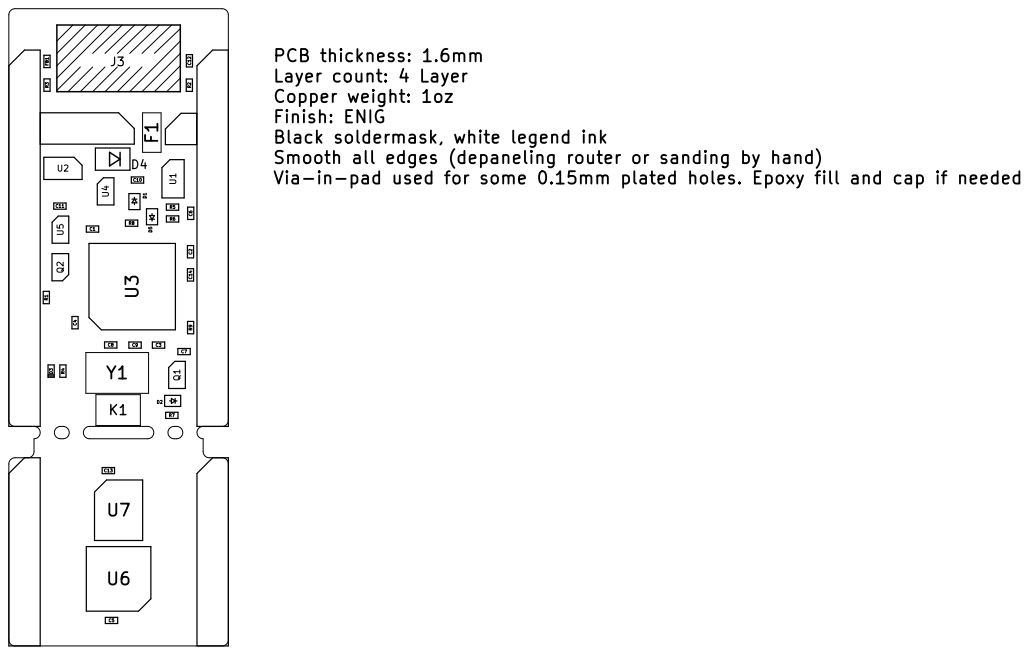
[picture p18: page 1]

Layer count: 4 Layer Copper weight: 1oz Finish: ENIG

Black soldermask, white legend ink Smooth all edges (depaneling router or sanding by hand) Via-in-pad used for some 0.15mm plated holes. Epoxy fill and cap if needed

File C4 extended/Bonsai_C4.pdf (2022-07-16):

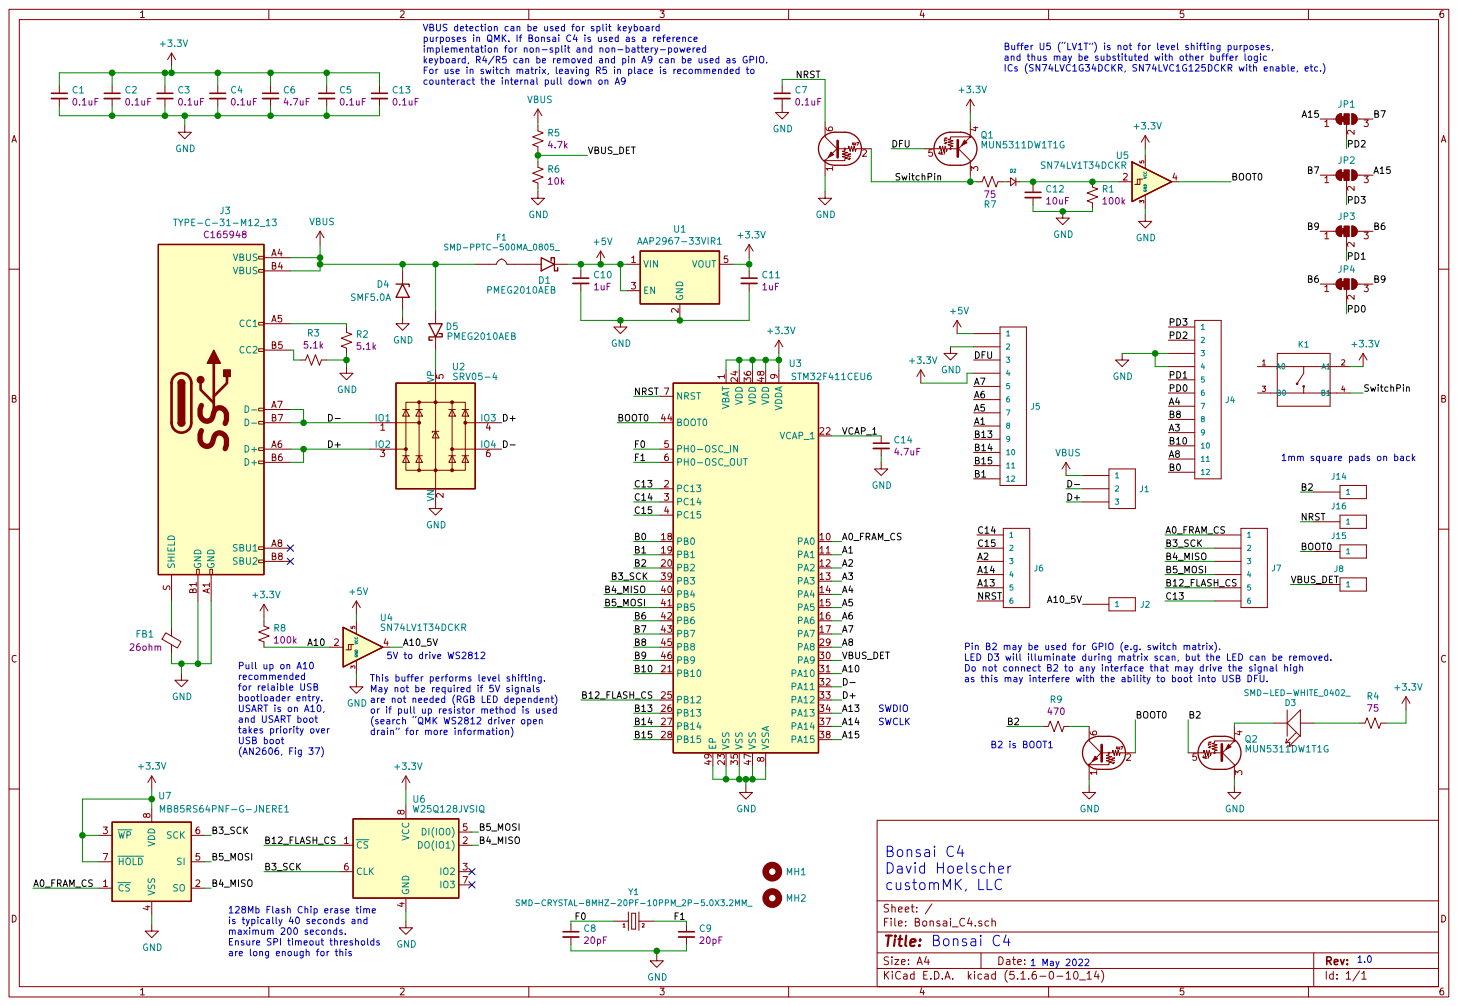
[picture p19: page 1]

VBUS detection can be used for split keyboard
purposes in QMK. If Bonsai C4 is used as a reference
implementation for non-split and non-battery-powered
keyboard, R4/R5 can be removed and pin A9 can be used as GPIO.
For use in switch matrix, leaving R5 in place is recommended to
counteract the internal pull down on A9

Buffer U5 (LV1T) is not for level shifting purposes,
and thus may be substituted with other buffer logic
ICs (SN74LVC1G34DCKR, SN74LVC1G125DCKR with enable, etc.)

2 EN 3 VOUT 5 U1 AAP2967-33VIR1 F1 SMD-PPTC-500MA_0805_ D1 PMEG2010AEB D5PMEG2010AEB D4 SMF5.0A GND

1 PA0 10 PA1 11 PA2 12 PA3 13 PA4 14 PA5 15 PA6 16 PA7 17 PB0 18 PB1 19 PC13 2 PB2 20 PB10 21 VCAP_1 22 VSS 23 VDD 24 PB12 25 PB13 26 PB14 27 PB15 28 PA8 29 PC14 3 PA9 30 PA10 31 PA11 32 PA12 33 PA13 34 VSS 35 VDD 36 PA14 37 PA15 38 PB3 39 PC15 4 PB4 40 PB5 41 PB6 42 PB7 43 BOOT0 44 PB8 45 PB9 46 VSS 47 VDD 48 EP 49 PH0-OSC_IN 5 PH0-OSC_OUT 6 NRST 7 VSSA

1mm square pads on back

Pin B2 may be used for GPIO (e.g. switch matrix).
LED D3 will illuminate during matrix scan, but the LED can be removed.
Do not connect B2 to any interface that may drive the signal high
as this may interfere with the ability to boot into USB DFU.

Pull up on A10
recommended
for relaible USB
bootloader entry. USART is on A10, and USART boot

B2 is BOOT1 This buffer performs level shifting.
May not be required if 5V signals
are not needed (RGB LED dependent)
or if pull up resistor method is used
(search QMK WS2812 driver open
drain for more information)

takes priority over USB boot (AN2606, Fig 37)

4 SI 5 SCK 6 HOLD 7 VDD

128Mb Flash Chip erase time
is typically 40 seconds and maximum 200 seconds. Ensure SPI timeout thresholds are long enough for this

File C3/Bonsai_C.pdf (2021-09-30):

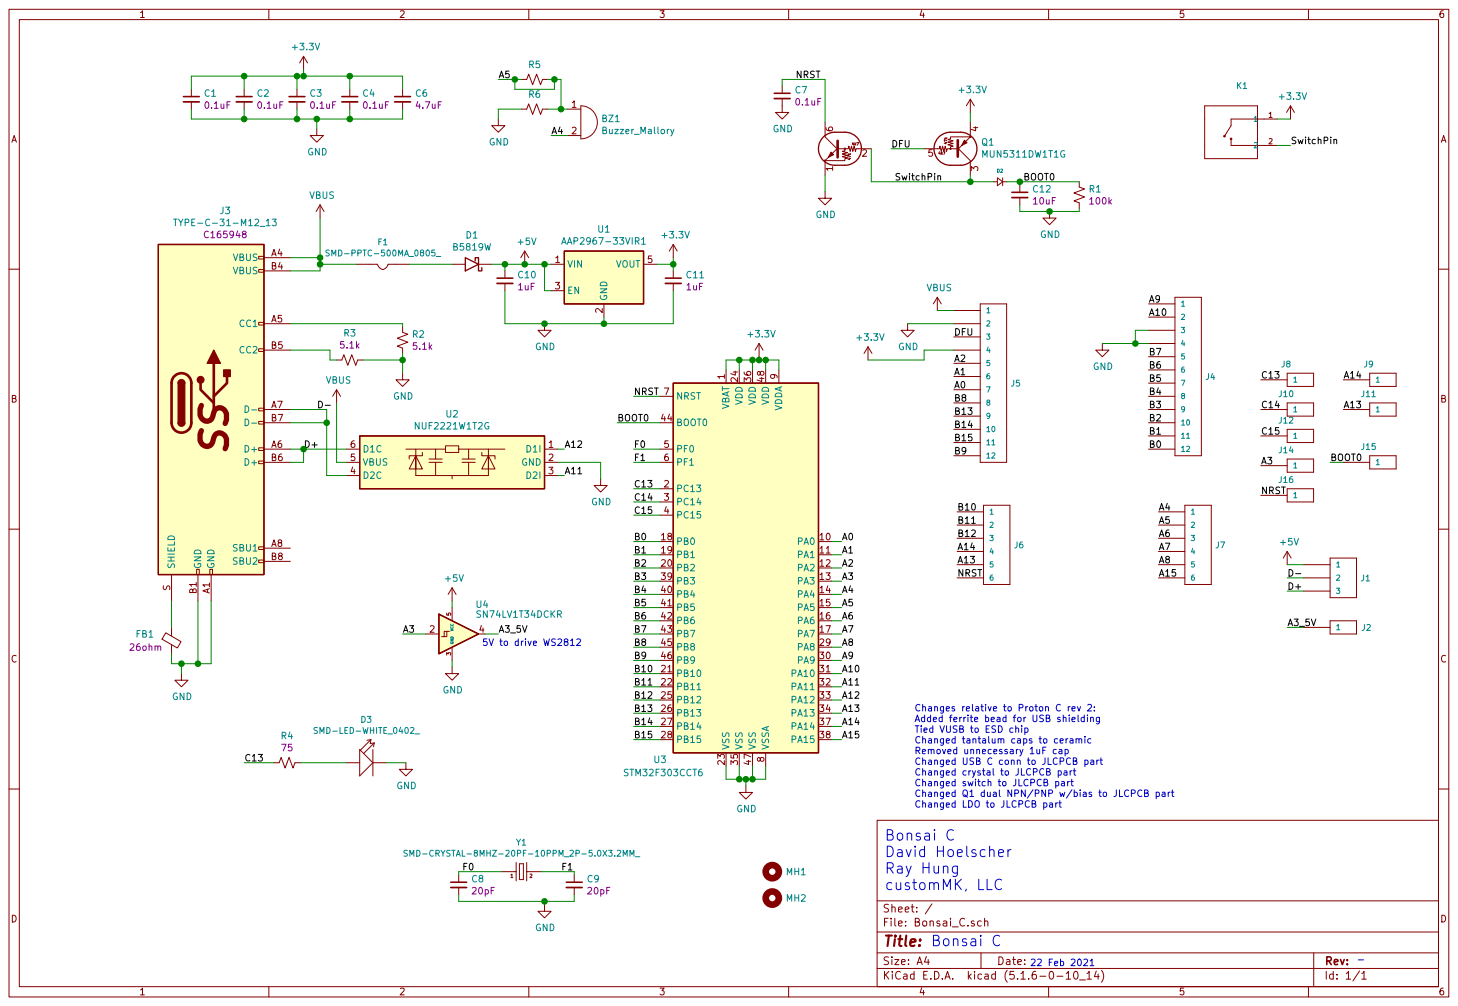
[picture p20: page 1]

1 PA0 10 PA1 11 PA2 12 PA3 13 PA4 14 PA5 15 PA6 16 PA7 17 PB0 18 PB1 19 PC13 2 PB2 20 PB10 21 PB11 22 VSS 23 VDD 24 PB12 25 PB13 26 PB14 27 PB15 28 PA8 29 PC14 3 PA9 30 PA10 31 PA11 32 PA12 33 PA13 34 VSS 35 VDD 36 PA14 37 PA15 38 PB3 39 PC15 4 PB4 40 PB5 41 PB6 42 PB7 43 BOOT0 44 PB8 45 PB9 46 VSS 47 VDD 48 PF0 5 PF1 6 NRST 7 VSSA

Changes relative to Proton C rev 2:
Added ferrite bead for USB shielding
Tied VUSB to ESD chip
Changed tantalum caps to ceramic
Removed unnecessary 1uF cap
Changed USB C conn to JLCPCB part
Changed crystal to JLCPCB part
Changed switch to JLCPCB part
Changed Q1 dual NPN/PNP w/bias to JLCPCB part
Changed LDO to JLCPCB part

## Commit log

2021-10-17 corrected JLCPCB version width to be 20mm
2021-11-06 Adding Bonsai C4. Schematic work-in-progress, layout TODO
    [Bonsai_C.kicad_pcb, Bonsai_C.sch, Bonsai_C4.kicad_pcb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]
2021-11-07 updated Bonsai C4 pinout to match sigprof's V0.1.2 recommendations
    [Bonsai_C4.sch]
2021-11-07 Corrected B4_MOSI to B4_MISO for Bonsai C4
    [Bonsai_C4.sch]
2021-11-09 Updated Bonsai C4 with reference implementation information
    [Bonsai_C4.sch]
2021-11-11 Swapped 5V and VBUS pins to match ProMicro and improved B2 pin wiring
    [Bonsai_C4.sch]
2021-11-13 Preliminary layout generated for Bonsai C4
    [Bonsai_C4.kicad_pcb, Bonsai_C4.sch]
2021-11-13 Bonsai C4 layout updates and adding solder pads for split keyboard support
    [Bonsai_C4.kicad_pcb, Bonsai_C4.sch]
2021-11-13 Updated Bonsai C4 schematic PDF
2021-11-13 Bonsai C4: corrected BOOT1 label to BOOT0
    [Bonsai_C4.kicad_pcb]
2021-11-13 Added pin labels to Bonsai C4
    [Bonsai_C4.kicad_pcb, Bonsai_C4.sch]
2022-01-29 Finalized pinout for best backwards compatibility with Promicro
    [Bonsai_C4.kicad_pcb, Bonsai_C4.sch]
2022-01-29 visual correction to Bonsai C4 schematic image
2022-01-30 swapped out 512kb FRAM for 64kb (8kB) FRAM. 512kb is supported, it's just a lot
    [Bonsai_C4.kicad_pcb, Bonsai_C4.sch]
2022-02-19 swapped RX/TX pins for better default support in split keyboards, cleaned up silkscreen
    [Bonsai C4 BOM.xlsx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]
2022-02-26 Added Bonsai C4 compact edition
    [Bonsai C4 BOM.xlsx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]
2022-03-25 Added JLCPCB build files for C4, modified C3 JLCPCB files, added schematic notes, updated readmes
    [Bonsai C4 BOM for JLCPCB.xlsx, Bonsai C4 BOM.xlsx, Bonsai_C-pos_JLCPCB.csv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]
2022-07-16 Added schematic symbols and footprints of Bonsai C4
    [Bonsai_C4.sch]
2022-07-16 Updated pin naming for Bonsai C4 schematic symbols
2022-08-26 Documentation clean up/organization, add photos and images
    [Bonsai C4 BOM.xlsx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]
2022-11-19 correct swapped pins in Bonsai C4 footprints
2023-07-08 corrected part number for 0402 capacitor in Bonsai C3 (was 0603 part with 0402 footprint)
    [Bonsai_C.kicad_pcb, Bonsai_C.sch]
2025-04-04 Add quotes for the silkscreen text
    [Bonsai_C4.kicad_pcb]
